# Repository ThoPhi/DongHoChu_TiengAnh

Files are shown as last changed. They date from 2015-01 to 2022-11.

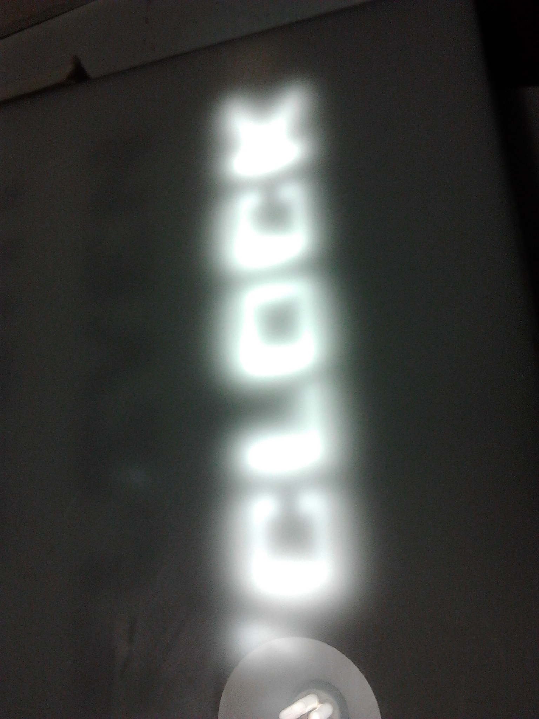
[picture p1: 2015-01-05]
Images/2014-12-19 17.24.27.jpg

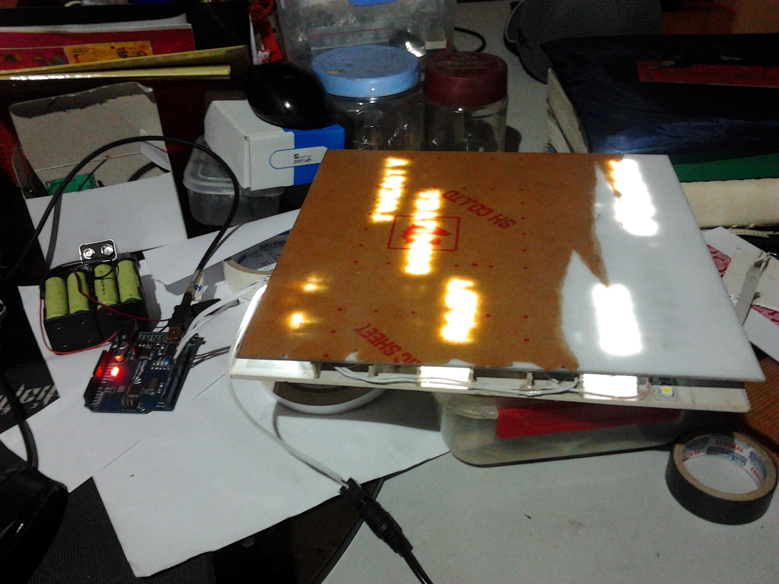
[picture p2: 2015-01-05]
Images/2014-12-19 15.56.30.jpg

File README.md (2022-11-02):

DongHoChu_TiengAnh
==================

Đồng hồ thay vì hiện số, bây giờ nó sẽ như một người bạn thông báo giờ bằng ngôn ngữ, tiếng Anh.
Tên gọi khác Dough Word Clock 

*Nguyên liệu
1. Arduino Pro mini 
2. led dây cắt khúc 
3. Module RTC 
4. Mạch mở rộng SPI-Paralell 595

* Các cụm từ: 
1. It's 
2. One
3. Two
4. Three 
5. Four 
6. Five 
7. Six 
8. Seven
9. Eight
10. Nine
11. Ten
12. Eleven 
13. Twelve 
14. quater 
15. half
16. to
17. past 
18. o'clock

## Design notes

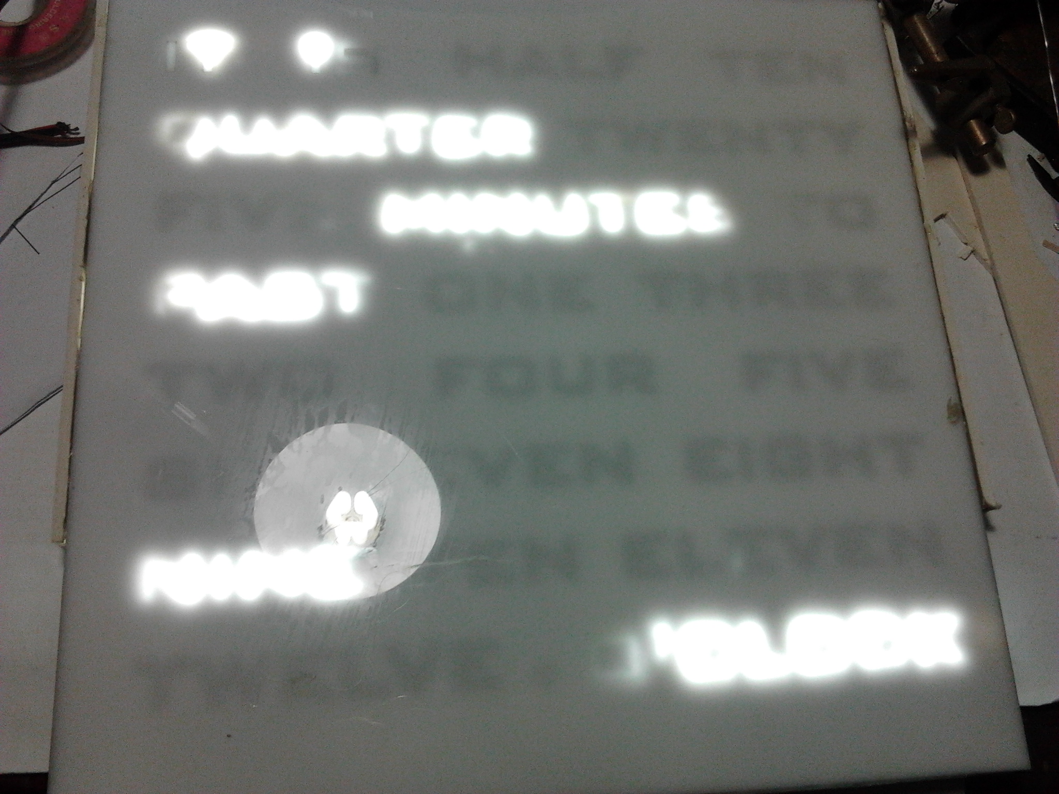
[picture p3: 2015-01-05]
Images/2014-12-19 17.24.07.jpg

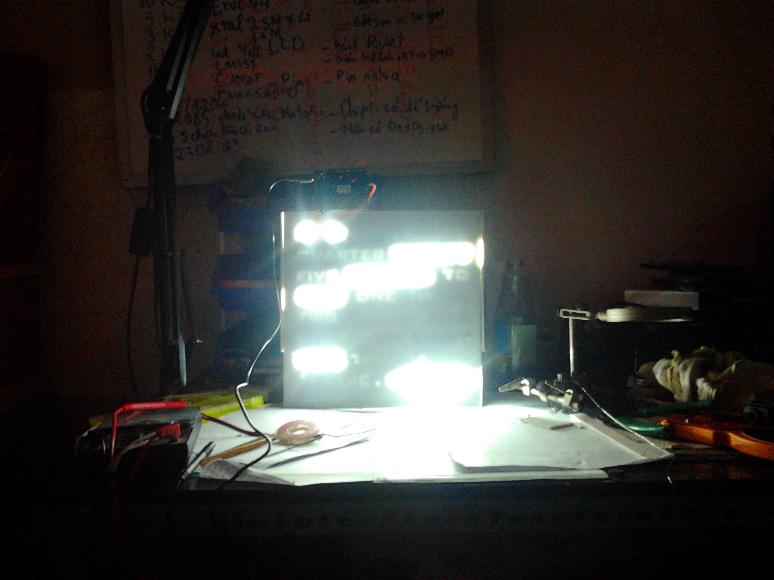
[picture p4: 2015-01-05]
Images/2014-12-19 17.26.16.jpg

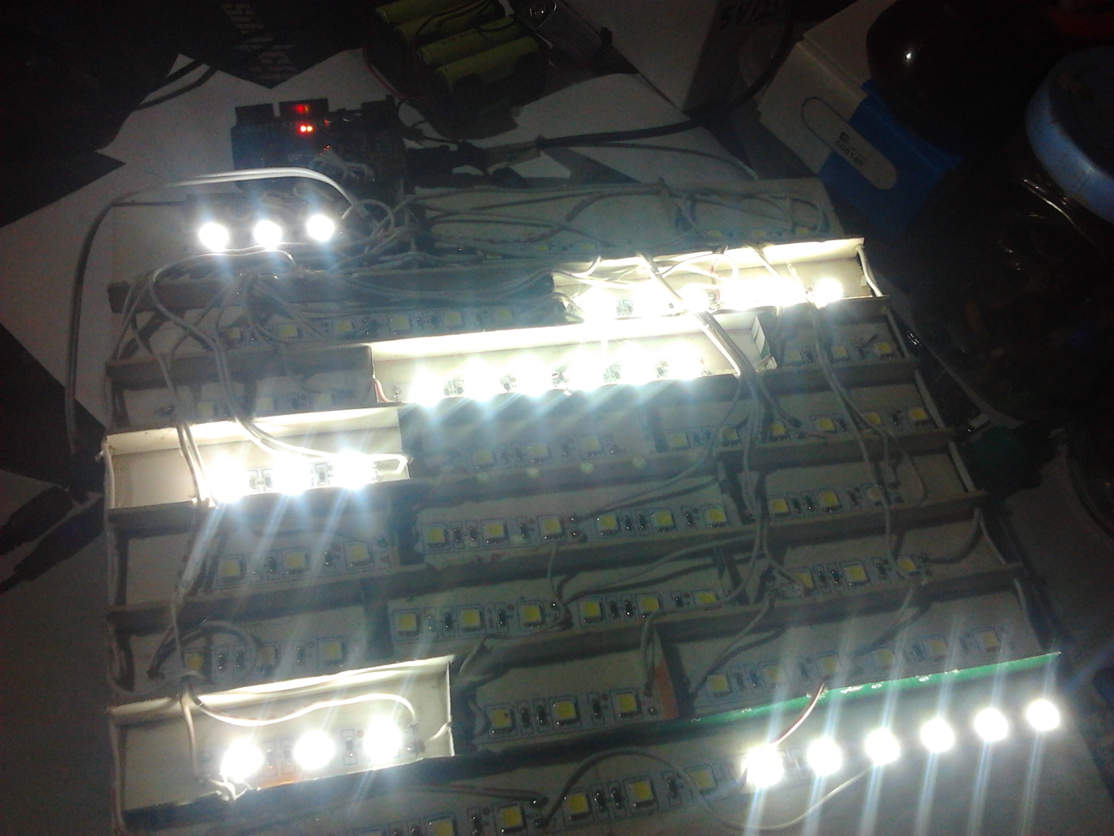
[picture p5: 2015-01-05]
Images/2014-12-19 15.56.41.jpg

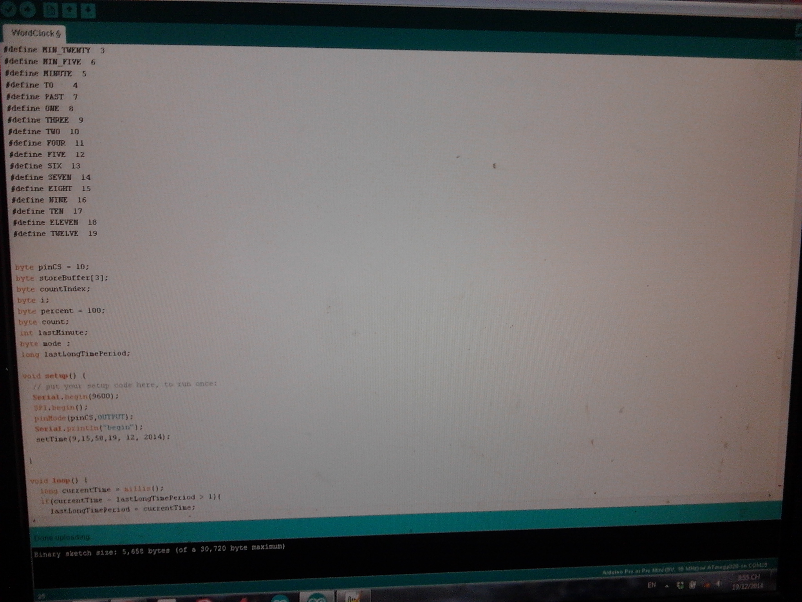
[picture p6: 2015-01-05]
Images/2014-12-19 15.57.28.jpg

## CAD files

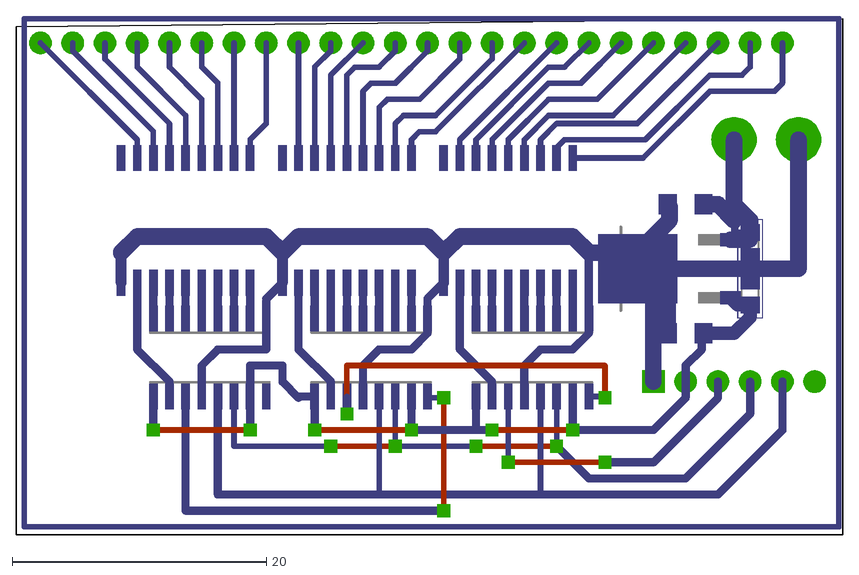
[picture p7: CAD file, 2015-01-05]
CircuitBuffer/ShiftCircuit.dxf
65.1 x 40.8

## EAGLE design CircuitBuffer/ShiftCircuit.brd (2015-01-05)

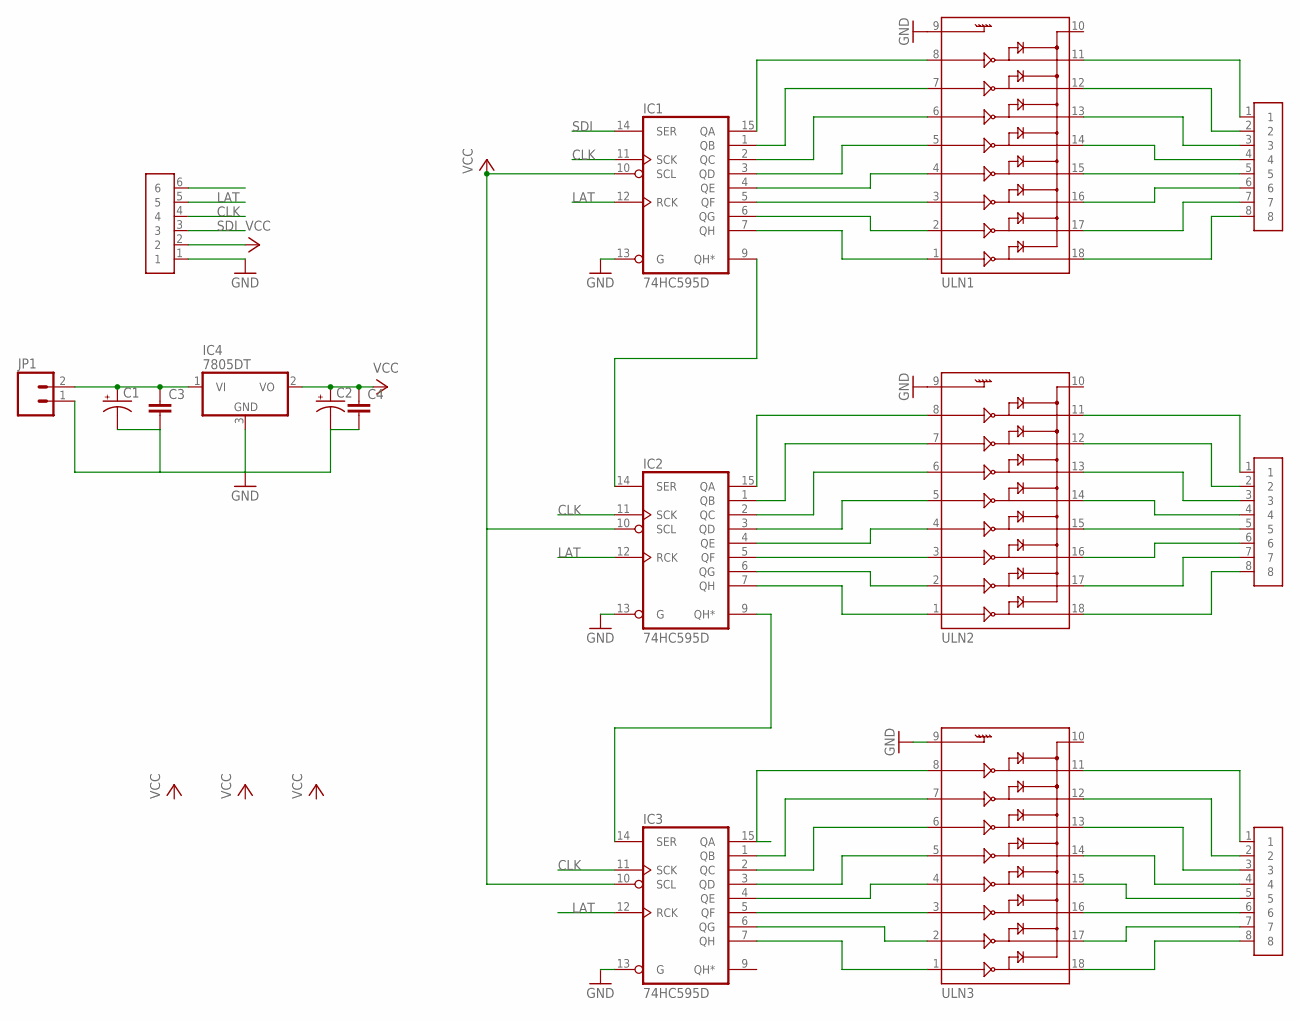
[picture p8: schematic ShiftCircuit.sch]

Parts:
C1, C2: CAP_POL1206; EIA3216
C3, C4: C-EUC0805; C0805
IC1, IC2, IC3: 74HC595D; SO16
IC4: 7805DT; TO252
JP1: M02PTH4; 1X02_XTRA_BIG
U$1, U$2, U$3: HEADER8
U$4: HEADER6
ULN1, ULN2, ULN3: ULN2803SOICW; SO18L

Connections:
CLK: IC1.11 (SCK), IC2.11 (SCK), IC3.11 (SCK), U$4.4
GND: C1.C (-), C2.C (-), C3.2, C4.2, IC1.8 (GND), IC1.13 (G), IC2.8 (GND), IC2.13 (G), IC3.8 (GND), IC3.13 (G), IC4.3 (GND), JP1.1, U$4.1, ULN1.9, ULN2.9, ULN3.9
LAT: IC1.12 (RCK), IC2.12 (RCK), IC3.12 (RCK), U$4.5
unnamed: IC1.15 (QA), ULN1.8
unnamed: IC1.1 (QB), ULN1.7
unnamed: IC1.2 (QC), ULN1.6
unnamed: IC1.3 (QD), ULN1.5
unnamed: IC1.4 (QE), ULN1.4
unnamed: IC1.5 (QF), ULN1.3
unnamed: IC1.6 (QG), ULN1.2
unnamed: IC1.7 (QH), ULN1.1
unnamed: IC1.9 (QH*), IC2.14 (SER)
unnamed: C1.A (+), C3.1, IC4.1 (VI), JP1.2
unnamed: IC2.15 (QA), ULN2.8
unnamed: IC2.1 (QB), ULN2.7
unnamed: IC2.2 (QC), ULN2.6
unnamed: IC2.3 (QD), ULN2.5
unnamed: IC2.4 (QE), ULN2.4
unnamed: IC2.9 (QH*), IC3.14 (SER)
unnamed: IC2.5 (QF), ULN2.3
unnamed: IC2.6 (QG), ULN2.2
unnamed: IC2.7 (QH), ULN2.1
unnamed: IC3.5 (QF), ULN3.3
unnamed: IC3.1 (QB), ULN3.7
unnamed: IC3.2 (QC), ULN3.6
unnamed: IC3.3 (QD), ULN3.5
unnamed: IC3.4 (QE), ULN3.4
unnamed: U$1.1, ULN1.11
unnamed: IC3.7 (QH), ULN3.1
unnamed: U$1.3, ULN1.13
unnamed: U$1.4, ULN1.14
unnamed: U$1.5, ULN1.15
unnamed: U$1.6, ULN1.16
unnamed: IC3.15 (QA), ULN3.8
unnamed: U$2.4, ULN2.14
unnamed: U$2.5, ULN2.15
unnamed: U$2.6, ULN2.16
unnamed: U$2.7, ULN2.17
unnamed: U$3.1, ULN3.11
unnamed: IC3.6 (QG), ULN3.2
unnamed: U$3.2, ULN3.12
unnamed: U$3.3, ULN3.13
unnamed: U$1.2, ULN1.12
unnamed: U$3.4, ULN3.14
unnamed: U$3.5, ULN3.15
unnamed: U$3.6, ULN3.16
unnamed: U$3.7, ULN3.17
unnamed: U$3.8, ULN3.18
unnamed: U$1.7, ULN1.17
unnamed: U$2.1, ULN2.11
unnamed: U$2.2, ULN2.12
unnamed: U$2.3, ULN2.13
unnamed: U$1.8, ULN1.18
unnamed: U$2.8, ULN2.18
SDI: IC1.14 (SER), U$4.3
VCC: C2.A (+), C4.1, IC1.10 (SCL), IC1.16 (VCC), IC2.10 (SCL), IC2.16 (VCC), IC3.10 (SCL), IC3.16 (VCC), IC4.2 (VO), U$4.2

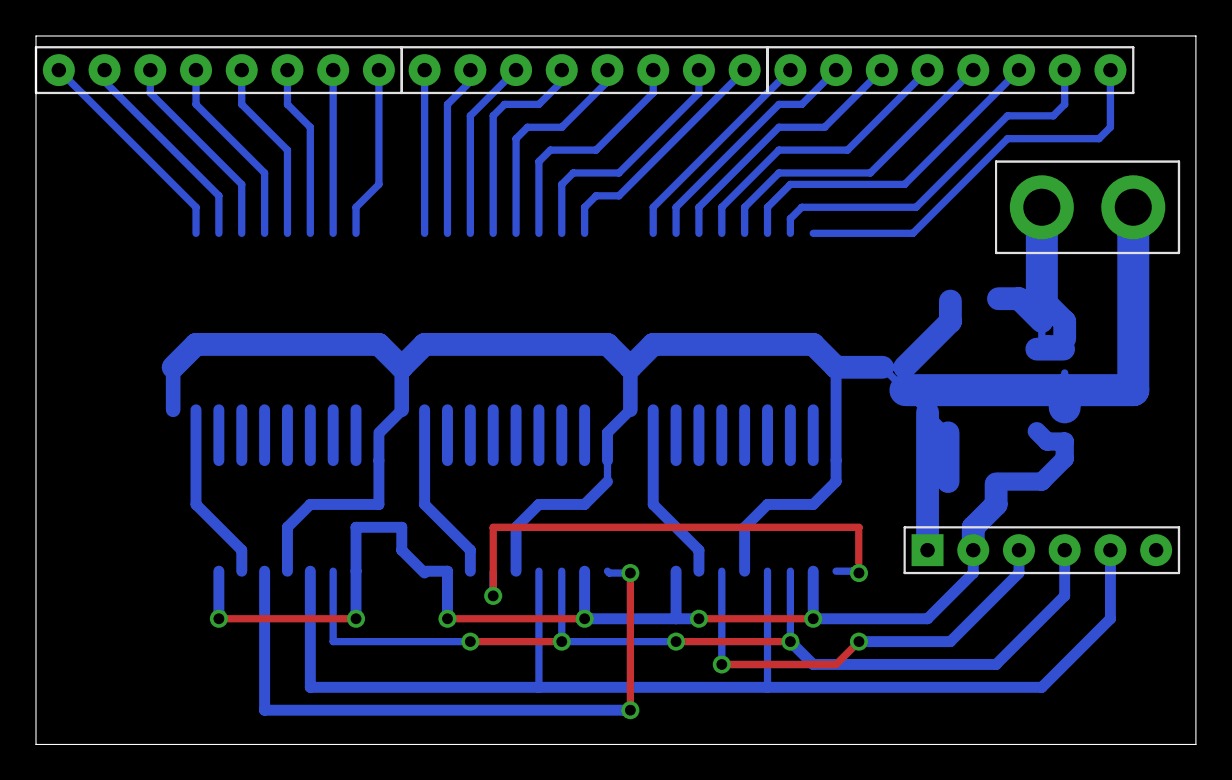
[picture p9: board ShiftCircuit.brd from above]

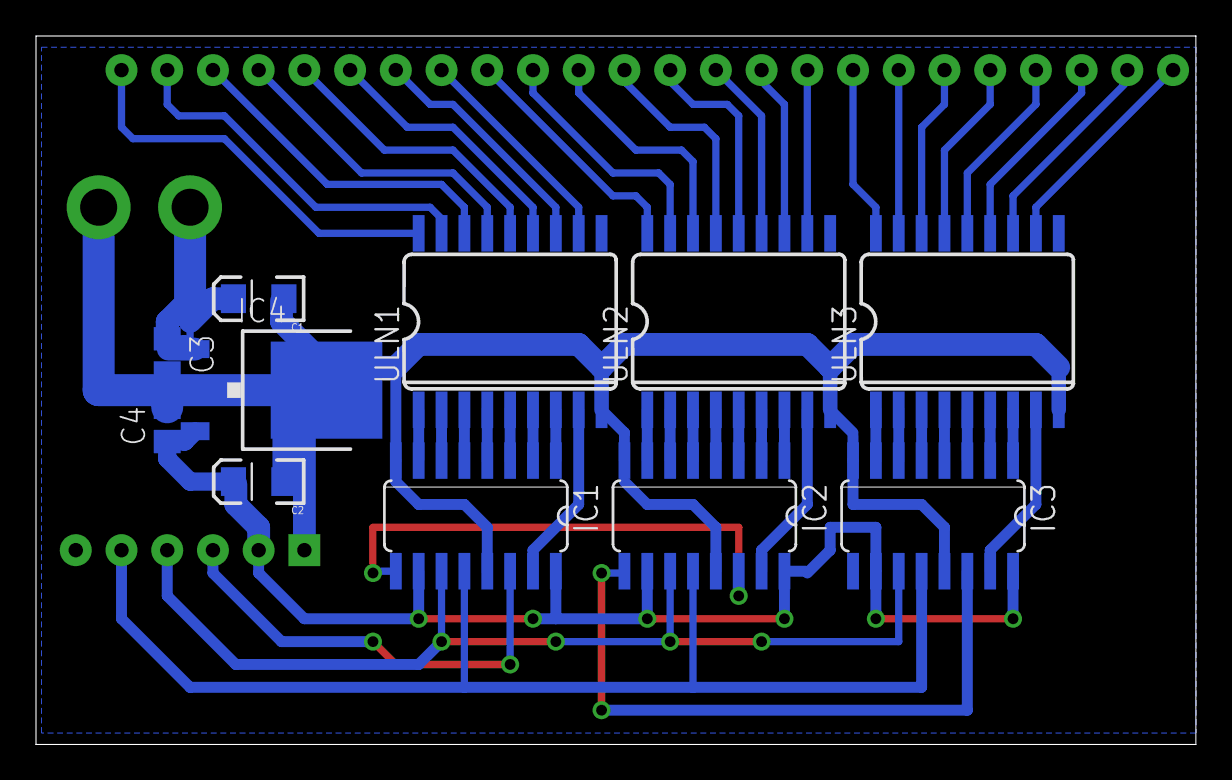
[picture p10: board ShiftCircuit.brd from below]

Board: 2 copper layers, 64.4 x 39.4 mm, 16 parts (11 on the bottom side), 56 nets.

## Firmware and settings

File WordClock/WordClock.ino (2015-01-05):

#include <Time.h>
#include <Wire.h>  
#include <DS1307RTC.h>
#include <SPI.h>

#define IT_IS  22
#define OCLOCK  21
#define MIN_HALF  1
#define MIN_TEN  0
#define MIN_QUARTER  2
#define MIN_TWENTY  3
#define MIN_FIVE  6
#define MINUTE  5
#define TO    4
#define PAST  7
#define ONE  8
#define THREE  9 
#define TWO  10
#define FOUR  11
#define FIVE  12 
#define SIX  13
#define SEVEN  14
#define EIGHT  15
#define NINE  16
#define TEN  17
#define ELEVEN  18
#define TWELVE  19

#define TIME_MSG_LEN  11   // time sync to PC is HEADER followed by unix time_t as ten ascii digits
#define TIME_HEADER  'T'   // Header tag for serial time sync message
#define TIME_REQUEST  7    // ASCII bell character requests a time sync message 

byte pinCS = 10;
byte storeBuffer[3];
byte countIndex;
byte i;
byte count;
int lastMinute;
byte mode ;
long lastLongTimePeriod;

void setup() {
  // put your setup code here, to run once:
  Serial.begin(9600);
  SPI.begin();
  pinMode(pinCS,OUTPUT);  
  Serial.print(TIME_REQUEST);  
  delay(1000);
  if(Serial.available()){
    processSyncMessage();
  }
  else setSyncProvider(RTC.get);   // the function to get the time from the RTC    
  //setTime(9,15,58,19, 12, 2014);

}

void loop() {
  long currentTime = millis();
  if(currentTime - lastLongTimePeriod > 1){
    lastLongTimePeriod = currentTime;
    if(mode ==0){
      time_process();
    }
  }  
  // put your main code here, to run repeatedly: 


}

void send_to_clock(){
  digitalWrite(pinCS,LOW);
  for(i=0;i<3;i++){
    SPI.transfer(storeBuffer[i]);
  }
  digitalWrite(pinCS,HIGH);
}

void clear_buffer(){
  for(byte i=0;i<3;i++){
    storeBuffer[i] = 0;
  }
}

void buffer_set(byte ledIndex){
  if (ledIndex >23) return;
  byte byteIndex = ledIndex/8;
  storeBuffer[byteIndex] |= 1<<(ledIndex%8); 
}

void time_process(){
  int currentHour = hour();
  int currentMinute = minute();
  if(lastMinute != currentMinute){
    Serial.print("Now is: ");
    Serial.print(currentHour);
    Serial.print(" ");
    Serial.println(currentMinute);

    clear_buffer();
    //minute display
    if(currentMinute >32){
      if(currentHour<23) currentHour ++;
      else currentHour = 1;

      switch(currentMinute){
      case 33 ... 37:
        buffer_set(MIN_TWENTY);
        buffer_set(MIN_FIVE);
                buffer_set(MINUTE);
        buffer_set(TO);
        break;
      case 38 ... 42:
        buffer_set(MIN_TWENTY);
        buffer_set(MINUTE);
        buffer_set(TO);
        break;
      case 43 ... 47:
        buffer_set(MIN_QUARTER);
        buffer_set(TO);
        break;
      case 48 ... 52:
        buffer_set(MIN_TEN);
        buffer_set(MINUTE);
        buffer_set(TO);
        break;
      case 53 ... 57:
        buffer_set(MIN_FIVE);
        buffer_set(MINUTE);
        buffer_set(TO);
        break;
      }
    }
    else{
      switch(currentMinute){
      case 3 ... 7:
        buffer_set(MIN_FIVE);      
        buffer_set(MINUTE);
        buffer_set(PAST);
        break;
      case 8 ... 12:
        buffer_set(MIN_TEN);
        buffer_set(MINUTE);
        buffer_set(PAST);
        break;
      case 13 ...17:
        buffer_set(MIN_QUARTER);
        buffer_set(PAST);
        break;
      case 18 ... 22:
        buffer_set(MIN_TWENTY);
        buffer_set(MINUTE);
        buffer_set(PAST);
        break;
      case 23 ... 27:
        buffer_set(MIN_TWENTY);
        buffer_set(MIN_FIVE);
        buffer_set(MINUTE);
        buffer_set(PAST);
        break;
      case 28 ... 32:
        buffer_set(MIN_HALF);
        buffer_set(PAST);        
        break;
      }
    }
    //hour display
    buffer_set(OCLOCK);
    currentHour %= 12 ;
    switch(currentHour){
    case 1:
      buffer_set(ONE);
      break;
    case 2:
      buffer_set(TWO);
      break;
    case 3:
      buffer_set(THREE);
      break;
    case 4:
      buffer_set(FOUR);
      break;
    case 5:
      buffer_set(FIVE);
      break;
    case 6:
      buffer_set(SIX);
      break;
    case 7:
      buffer_set(SEVEN);
      break;
    case 8:
      buffer_set(EIGHT);
      break;
    case 9:
      buffer_set(NINE);
      break;
    case 10:
      buffer_set(TEN);
      break;
    case 11:
      buffer_set(ELEVEN);
      break;
    case 0:
      buffer_set(TWELVE);
      break;
    }
    buffer_set(IT_IS);
    buffer_set(OCLOCK);
    send_to_clock();  
  }
  lastMinute = currentMinute;
}

void processSyncMessage() {
 //if time sync available from serial port, update time and return true
  while(Serial.available() >=  TIME_MSG_LEN ){  // time message consists of a header and ten ascii digits
    char c = Serial.read() ; 
    Serial.print(c);  
    if( c == TIME_HEADER ) {       
      time_t pctime = 0;
      for(int i=0; i < TIME_MSG_LEN -1; i++){   
        c = Serial.read();          
        if( c >= '0' && c <= '9'){   
          pctime = (10 * pctime) + (c - '0') ; // convert digits to a number    
        }
      }   
      setTime(pctime);   // Sync Arduino clock to the time received on the serial port
      RTC.set(now());
    }  
  }
}
